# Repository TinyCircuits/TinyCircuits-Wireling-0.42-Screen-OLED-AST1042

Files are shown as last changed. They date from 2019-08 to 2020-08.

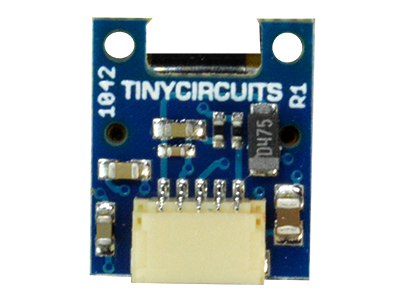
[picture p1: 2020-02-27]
images/AST1042-Learn-Photo-02.png

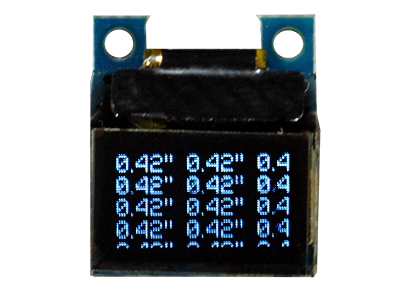
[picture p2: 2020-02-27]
images/AST1042-Learn-Photo-01.png

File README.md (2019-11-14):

# TinyCircuits Wireling 0.42 Screen OLED
# AST1042 Rev1

The design files are located under design_files/ for the TinyCircuits AST1042 Rev 1 PCB. This is a Wireling board which is the smallest our line has to offer, still packing an impressive 72 x 40 pixels in a 0.42" package for all your tiny display needs.

Format is in Cadsoft Eagle format - Eagle version 6.2 was used for the original design.

For more infomation on this, check out the product page at TinyCircuits.com

# License:

Design by TinyCircuits.
All design files are released under the Creative Commons Attribution Share-Alike 3.0 License, see the following link for details: http://creativecommons.org/licenses/by-sa/3.0

All text above must be included in any redistribution or derived design

This project uses designs and concepts developed as part of the Arduino project and the LilyPad project.  The TinyCircuits design files themselves (schematics, PCB and libraries) are not directly derived from these works' design files and have been created new, however the concepts and basic architecture behind the TinyDuino and TinyLily products are derived and we thank the hard work of the organizations below for their contributions to open-source hardware:
  
Original Arduino Uno Design by Team Arduino

LilyPad Arduino Design by Leah Buechley and Sparkfun Electronics

Please support the open-source hardware community

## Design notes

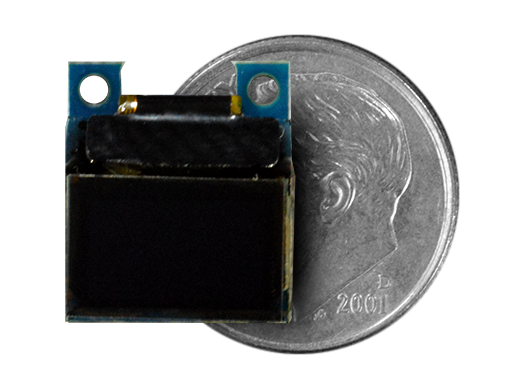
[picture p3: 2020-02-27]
images/AST1042-Product-Photo-03.png

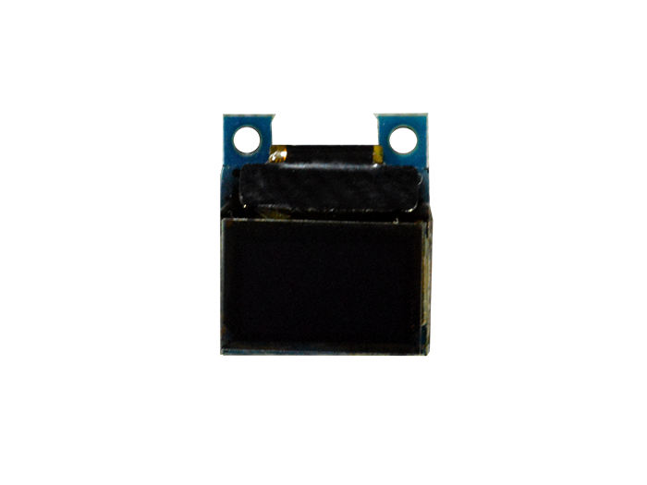
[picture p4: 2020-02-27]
images/AST1042-Product-Photo-01.png

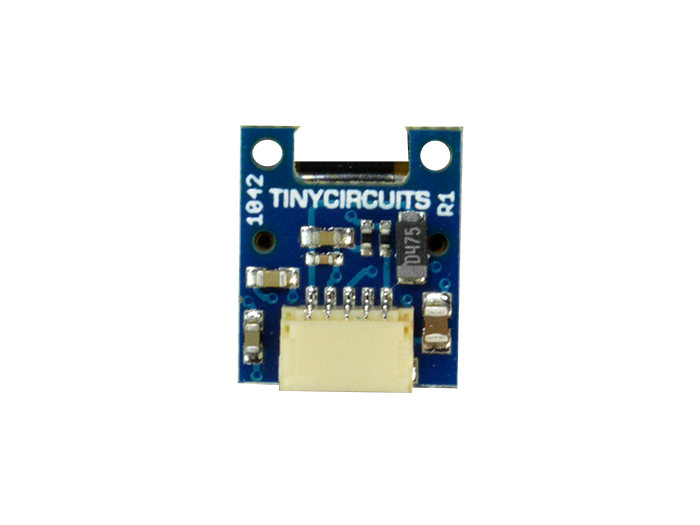
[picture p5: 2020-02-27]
images/AST1042-Product-Photo-02.png

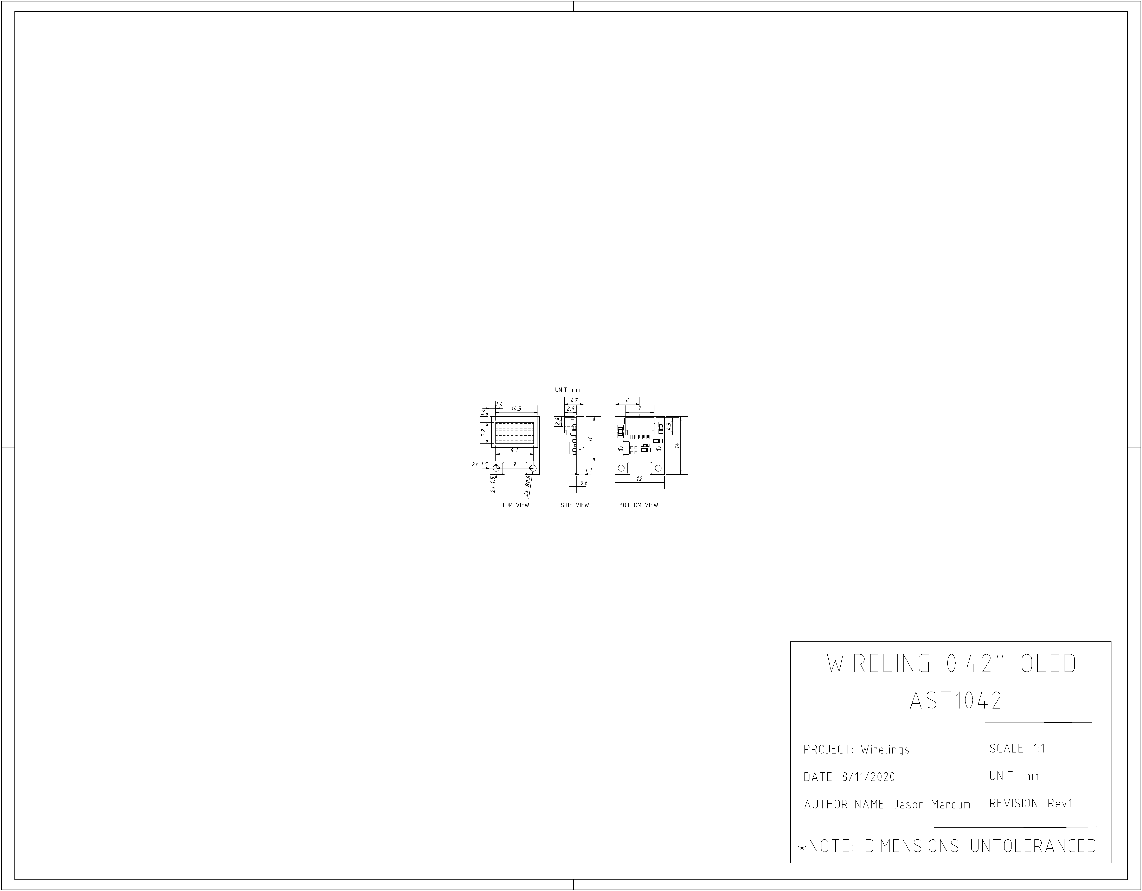
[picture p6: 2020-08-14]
cad/Wireling_042OLED_AST1042_REV1-DETAILED_DRAWING-PNG.png

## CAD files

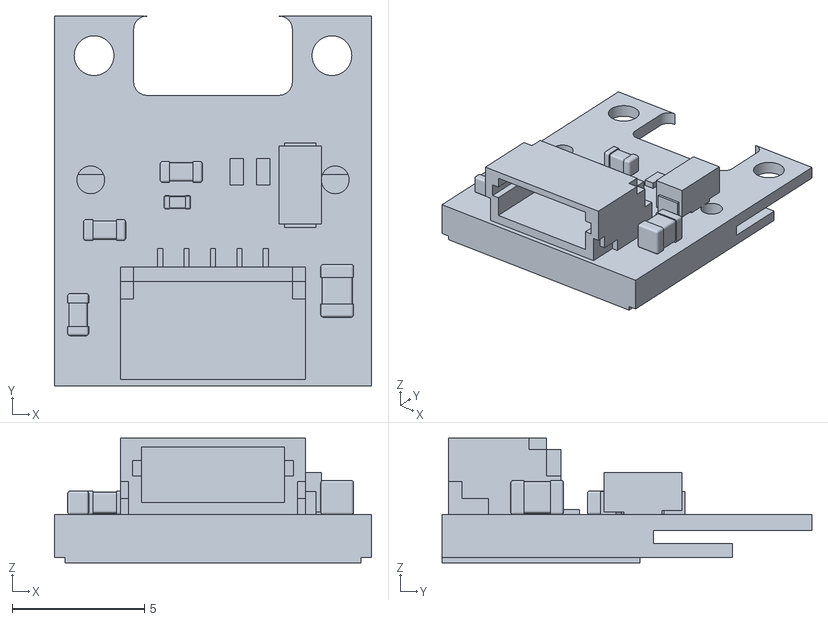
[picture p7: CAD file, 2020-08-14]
cad/Wireling_042OLED_AST1042_REV1-STL.stl
12.0 x 14.0 x 4.72

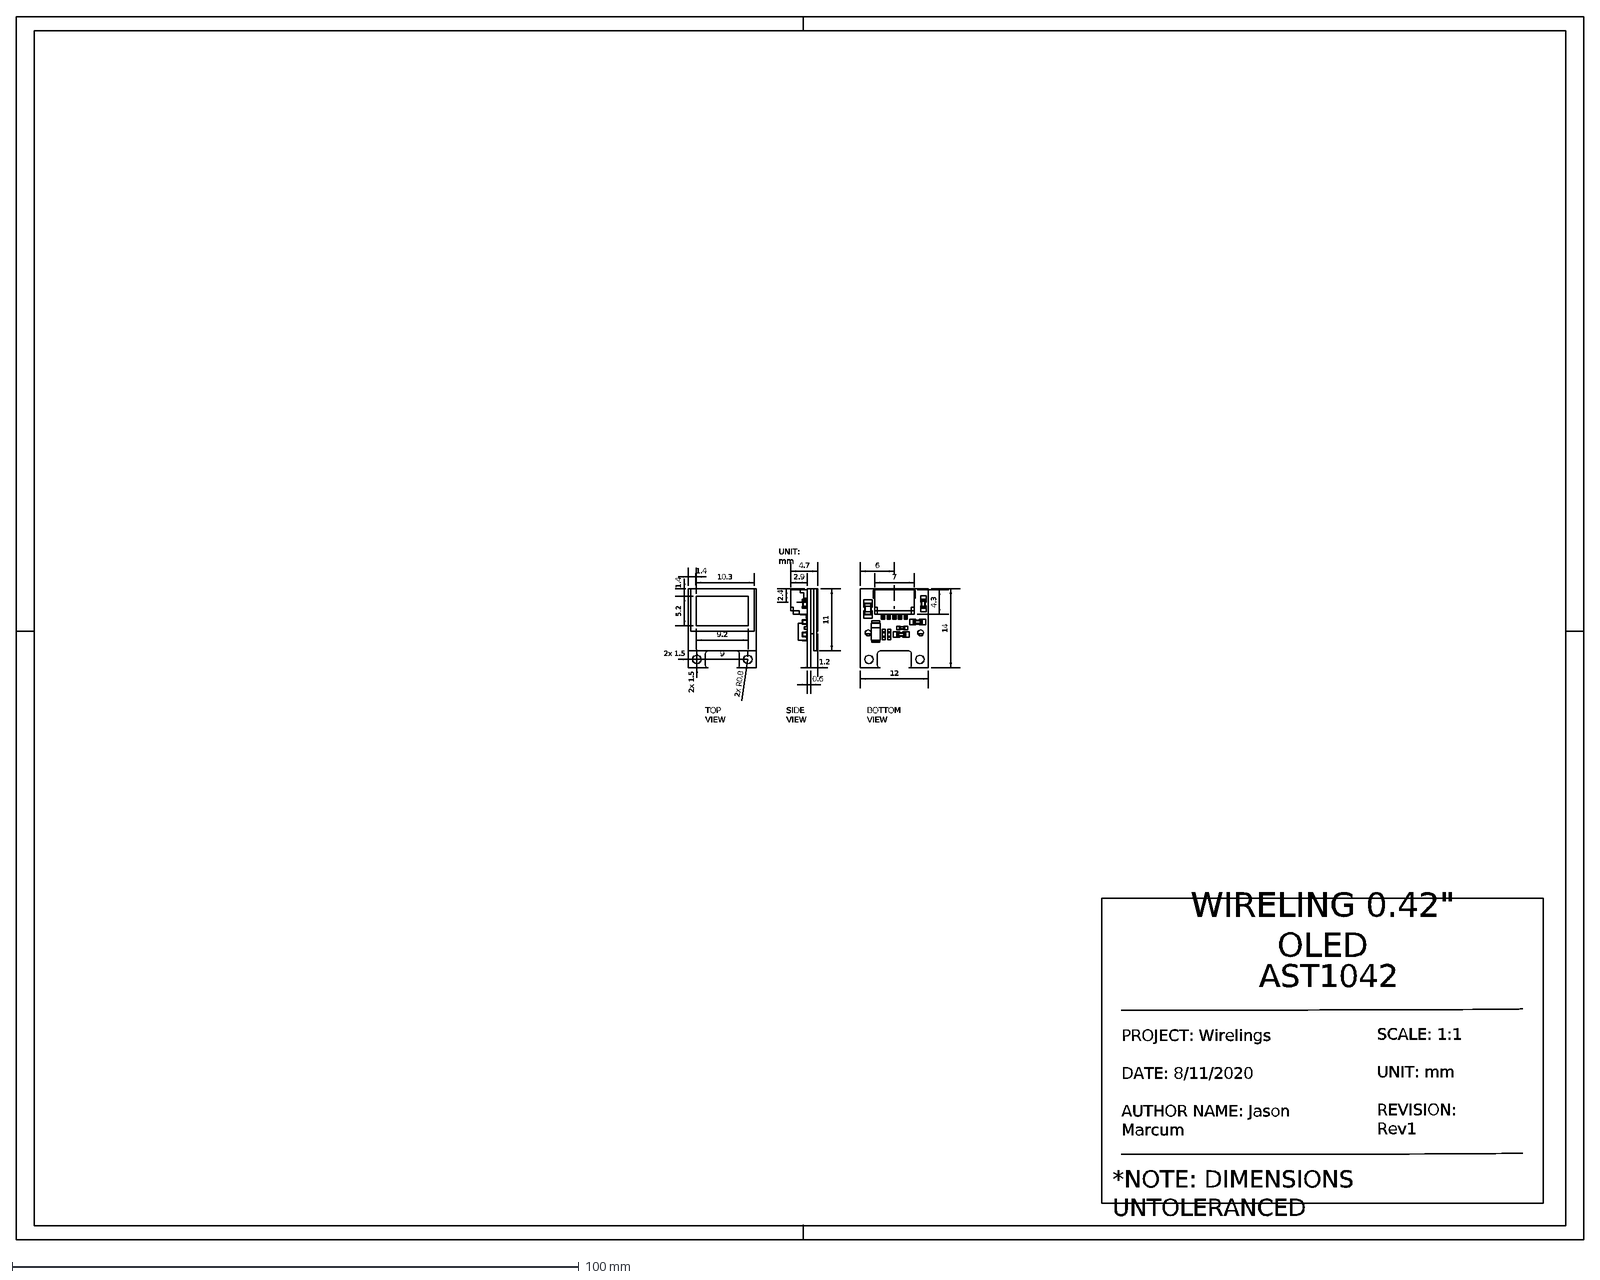
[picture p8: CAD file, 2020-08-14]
cad/Wireling_042OLED_AST1042_REV1-DETAILED_DRAWING-DXF.dxf
*NOTE: DIMENSIONS UNTOLERANCED
SCALE: 1:1 UNIT: mm REVISION: Rev1
TOP VIEW
BOTTOM VIEW
SIDE VIEW
5.2
1.4
2x 1.5
9
2x R0.8
2.4
2.9
4.7
UNIT: mm
1.2
10.3
11
7
6
4.3
14
9.2
0.6
WIRELING 0.42" OLED
AST1042
PROJECT: Wirelings DATE: 8/11/2020 AUTHOR NAME: Jason Marcum
12

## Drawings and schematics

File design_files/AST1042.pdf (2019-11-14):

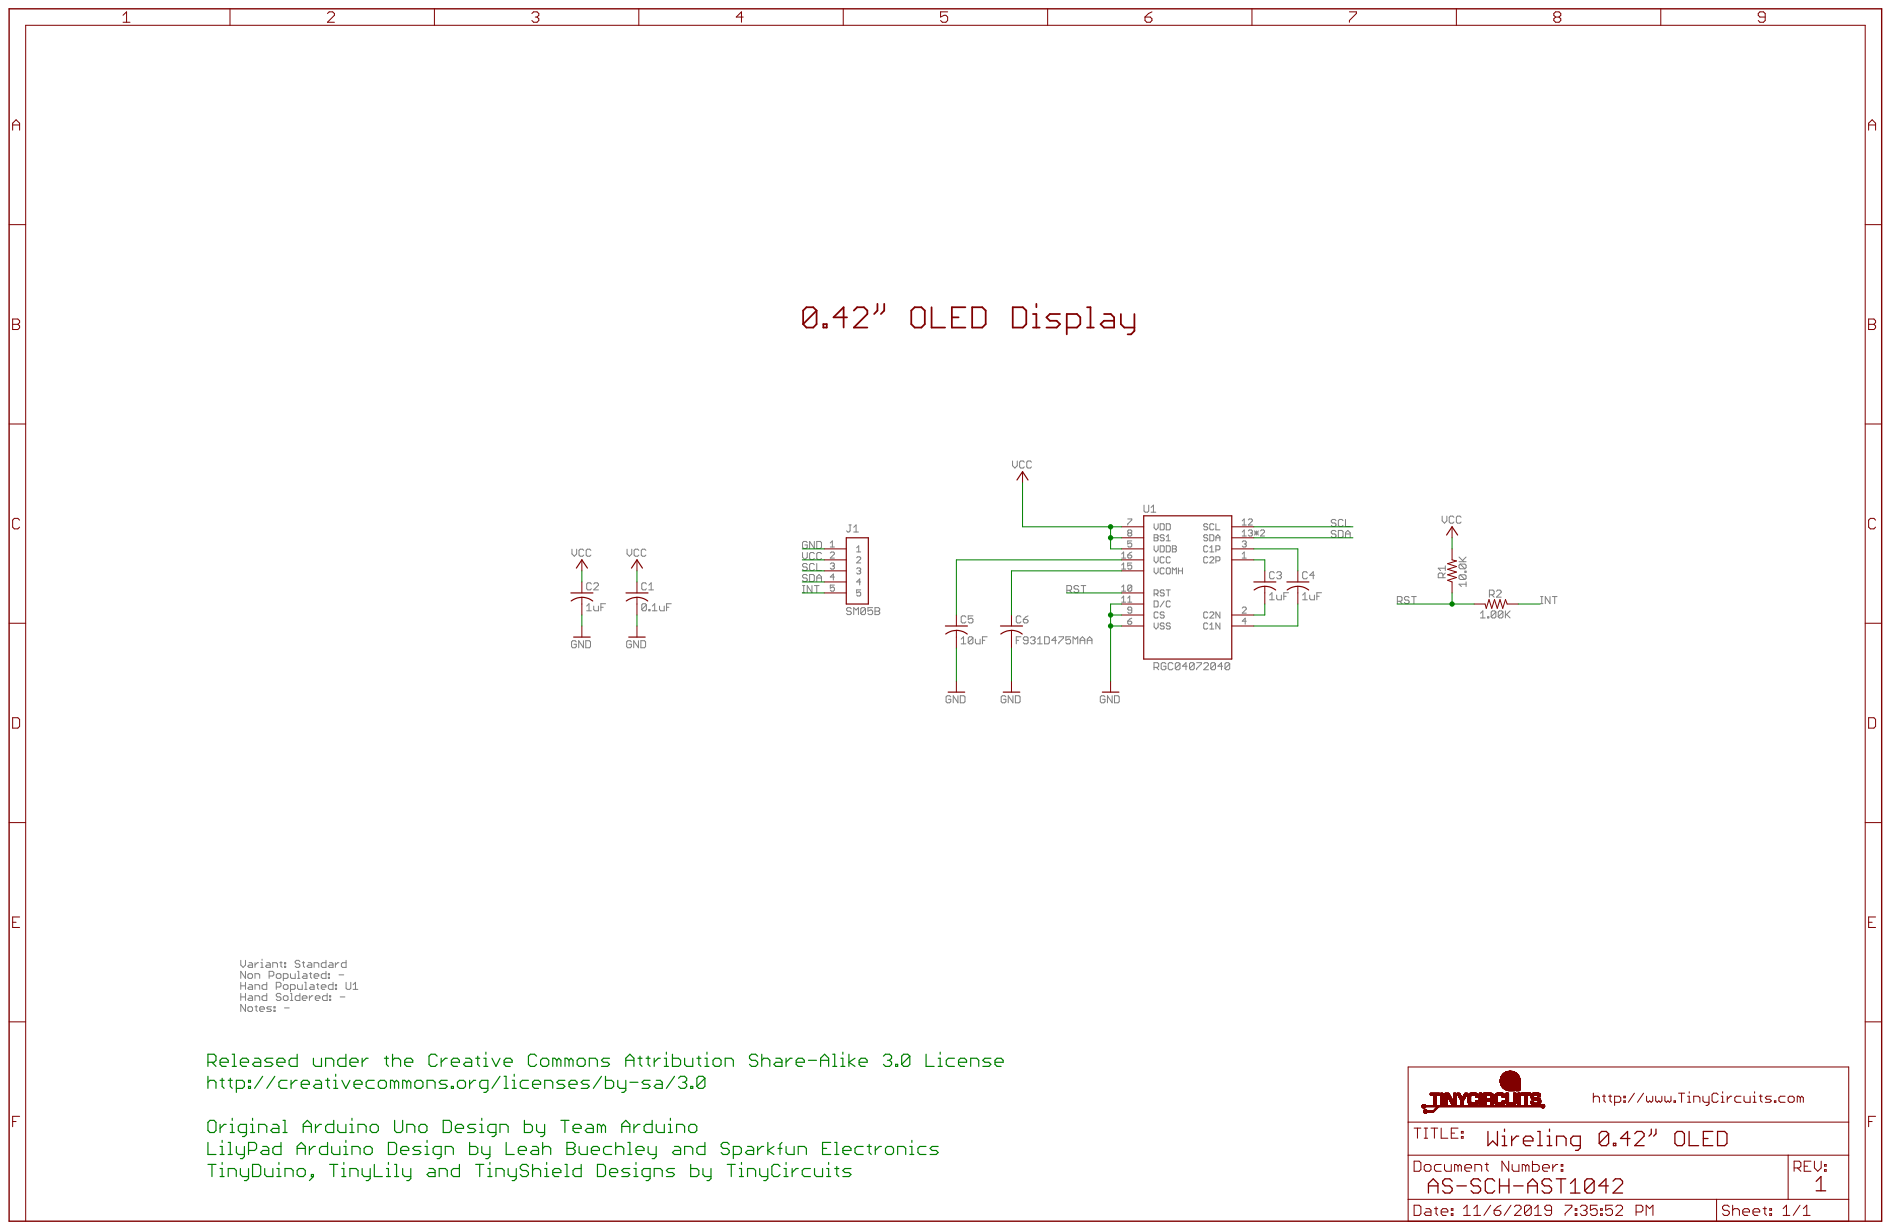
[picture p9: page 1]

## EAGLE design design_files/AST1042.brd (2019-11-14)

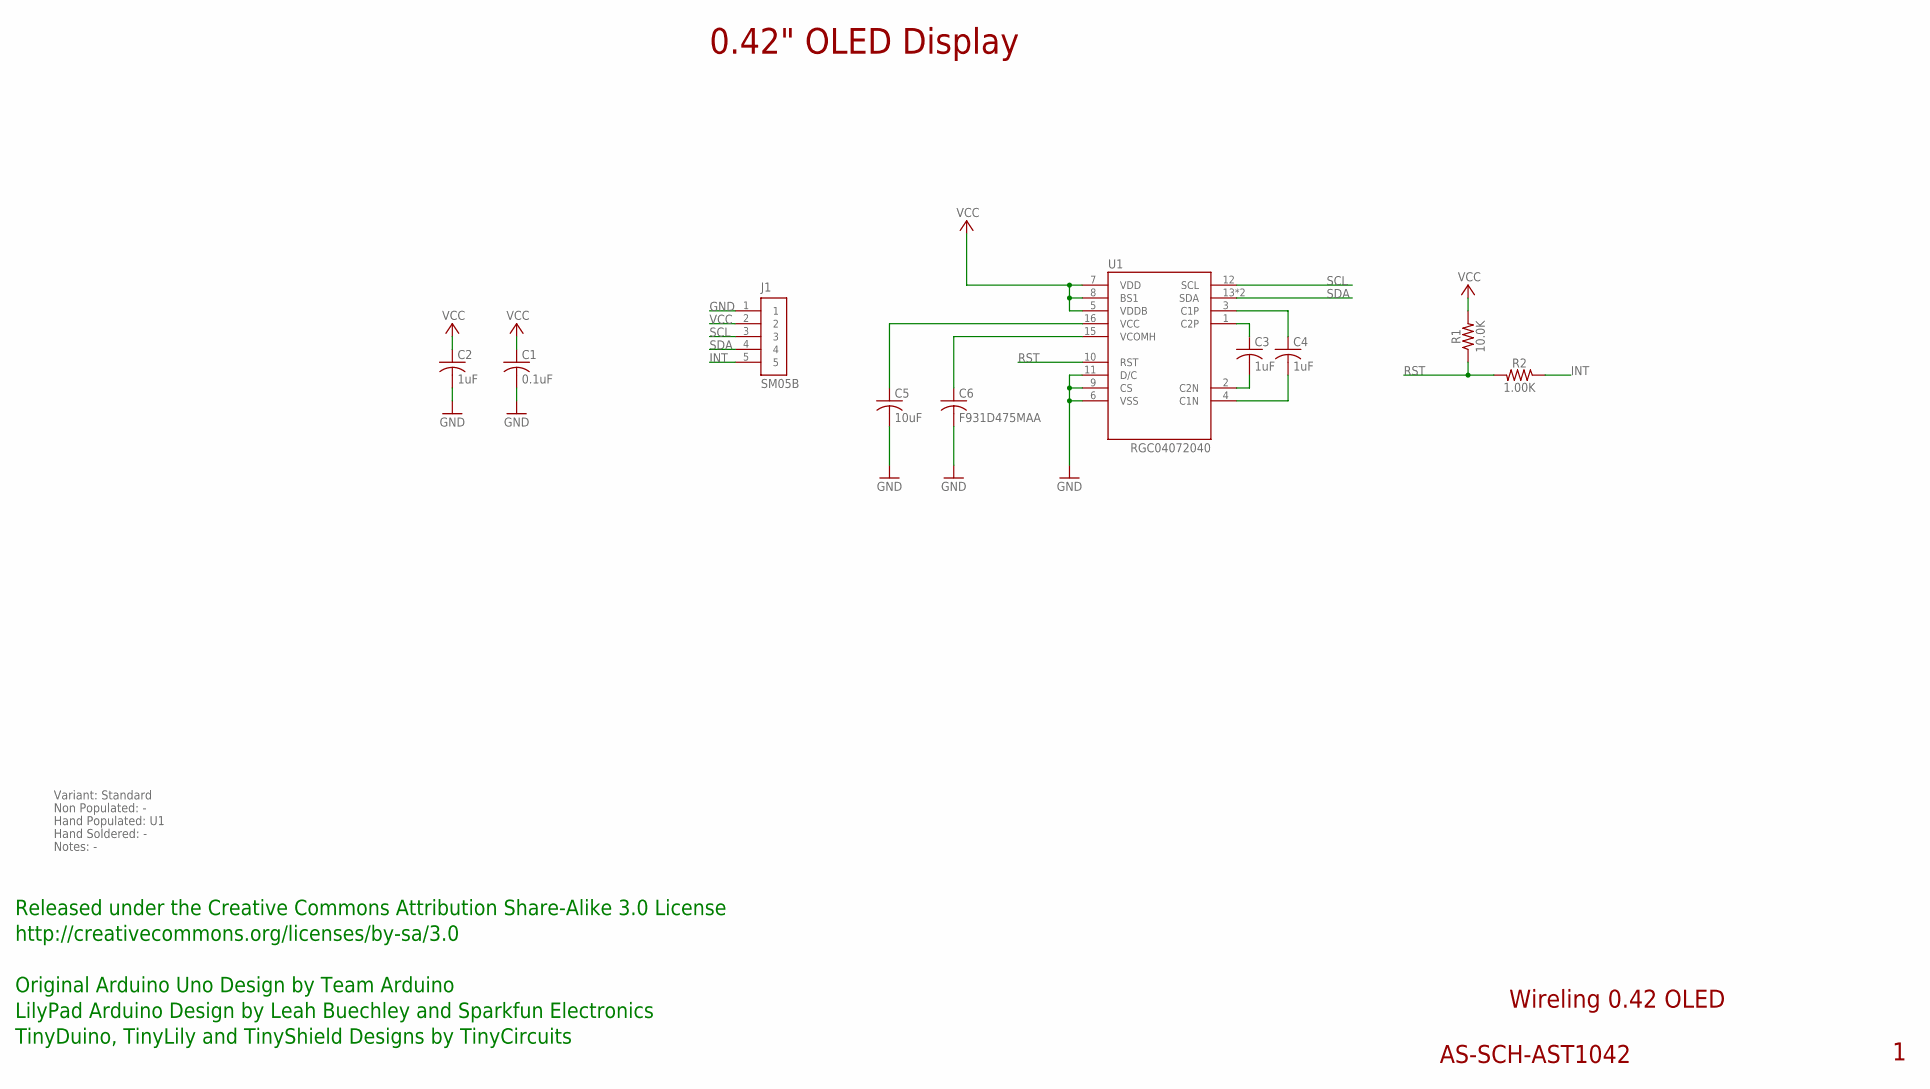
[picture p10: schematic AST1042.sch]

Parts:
C1: 0.1uF; C0402
C2: 1uF; C0603; PARTNO AS-ITM-00410
C3, C4: 1uF; C0603
C5: 10uF; C0805
C6: F931D475MAA; 1206_CAP_TANT
J1: SM05B; JST_SH_5X1_EDGE
R1: 10.0K; 0402
R2: 1.00K; 0402; PARTNO AS-ITM-00003
U1: RGC04072040; OLED_042

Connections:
GND: C1.2, C2.2, C5.2, C6.2, J1.1, U1.6 (VSS), U1.9 (CS), U1.11 (D/C)
INT: J1.5, R2.1
unnamed: C6.1, U1.15 (VCOMH)
unnamed: C3.1, U1.1 (C2P)
unnamed: C5.1, U1.16 (VCC)
unnamed: C4.1, U1.3 (C1P)
unnamed: C3.2, U1.2 (C2N)
unnamed: C4.2, U1.4 (C1N)
RST: R1.1, R2.2, U1.10 (RST)
SCL: J1.3, U1.12 (SCL)
SDA: J1.4, U1.13 (SDA), U1.14 (SDA)
VCC: C1.1, C2.1, J1.2, R1.2, U1.5 (VDDB), U1.7 (VDD), U1.8 (BS1)

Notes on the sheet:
Wireling 0.42 OLED
AS-SCH-AST1042
0.42" OLED Display
Released under the Creative Commons Attribution Share-Alike 3.0 License
http://creativecommons.org/licenses/by-sa/3.0
Original Arduino Uno Design by Team Arduino
TinyDuino, TinyLily and TinyShield Designs by TinyCircuits
LilyPad Arduino Design by Leah Buechley and Sparkfun Electronics
Non Populated: -
Hand Populated: U1
Hand Soldered: -
Variant: Standard
Notes: -

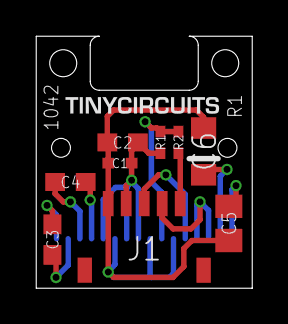
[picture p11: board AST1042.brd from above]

Board: 2 copper layers, 12.0 x 14.0 mm, 11 parts (1 on the bottom side), 12 nets.

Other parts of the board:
U$1: DOCFIELD-TINYCIRCUITS-PCB

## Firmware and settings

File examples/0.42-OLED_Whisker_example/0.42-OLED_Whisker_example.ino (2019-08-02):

/************************************************************************
 * HP7240 WhiskerBoard 0.42" OLED Display Demo/Test Code -
 * This code will display text and a Sprite at the same time when compiled. 
 *
 * Hardware by: TinyCircuits
 * Written by: Ben Rose, Laverena Wienclaw, & Hunter Hykes for TinyCircuits
 *
 * Initiated: Mon. 11/20/2017 
 * Updated: Tue. 08/02/2019
 ************************************************************************/

#include <Wire.h>                   // For I2C communication
#include <TinyScreen.h>             // For interfacing with TinyScreen+
#include "Font_042.h"               // The font displayed on the screen
#include "TinyCircuits_HP7240.h"    // Library for OLED screen
#include "exampleSprites.h"         // Holds arrays of example Sprites

#define SCREEN_PORT 0               // Port used by the 0.42 OLED Whisker
#define RESET_PIN (uint8_t)A0       // A0 corresponds to Port 0. Update if changing ports.
                                    // Port1: A1, Port2: A2, Port3: A3
// Variable for the 0.42" Whisker screen
TinyCircuits_HP7240 TiniestScreen;

#define xMax TiniestScreen.xMax
#define yMax TiniestScreen.yMax

TinyScreen display = TinyScreen(TinyScreenPlus);

// This is the data structure for a TinyScreen Sprite
typedef struct {
  int x;             // X coordinate (top left corner) of where Sprite is placed on screen initially 
  int y;             // Y coordinate (top left corner) of where Sprite is placed on screen initially 
  int width;         // Wideness of Sprite
  int height;        // Height of Sprite
  int bitmapNum;     // Index of animation stage of Sprite (only used when a Sprite is animated)
  const unsigned int * bitmap; // The array of 0's and 1's that determines appearance of Sprite
} Sprite;

Sprite bunnySprite = {0, 0, 13, 13, 0, bunnyBitmap};
Sprite duckSprite = {59, 3, 13, 10, 0, duckBitmap};
int amtSprites = 2; 
Sprite * spriteList[2] = {
  &bunnySprite, &duckSprite
};

uint8_t oledbuf[HP7240_BUFFERSIZE]; // Buffer to hold screen data

int bufIndex = 0; // Buffer index in respect to the array of pixels on the screen
int textPos = 0;  // Used to make text move left or right

int bunnySpeed = 2;
int bleh = 0;

void setup() {
  SerialUSB.begin(9600);
  pinMode(4, OUTPUT);
  digitalWrite(4, HIGH); // power Whisker Adapter TinyShield
  delay(10);

  TiniestScreen.begin();    // begin I2C communications with screen
  selectPort(SCREEN_PORT);  // This port# matches the one labeled on the adapter board
  TiniestScreen.resetScreen(RESET_PIN);   // resets whisker screen MUST BE CALLED BEFORE init()
  TiniestScreen.init();     // initialize screen
  clearOLED();              // Clear Display Buffer, isn't fully cleared here, frame buffer must be sent
  delay(2);
  TiniestScreen.sendFramebuffer(oledbuf); // Send Cleared Buffer

  // Initialize appearance of TinyScreen
  display.begin();
  display.setFlip(true);
  display.setBrightness(15);
  display.setFont(thinPixel7_10ptFontInfo);
  display.fontColor(TS_8b_White, TS_8b_Black); // white text, black background
  display.setCursor(0, 0);
  display.print("0.42 OLED Test");
  
}

// Clear the screen, put new text on the screen -> clear to create scrolling effect 
void loop() {
  clearOLED();
  drawSprites();
  
  textPos = 3*72;
  TiniestScreen.setCursorX(textPos);
  
  TiniestScreen.printSSD(oledbuf, "Bun and Duck"); // text must be written after sprites
  
  TiniestScreen.sendFramebuffer(oledbuf);
}

void selectPort(int port) {
  Wire.beginTransmission(0x70);
  Wire.write(0x04 + port);
  Wire.endTransmission(0x70);
}

/* The OLED screen is 72 by 40 pixels. The screen uses x and y coordinates,
   but with the twist that the 0,0 point is at the top left:

   **************************************************************************
   |  (0,0), (1,0), (...)                                            (71, 0)|
   |  (0,1),                                                                |
   |  (...)                                                                 |
   |                                                                        |
   |                                                                        |
   |                                                                        |
   |  (0,39)                                                         (71,39)|
   **************************************************************************
                              (Not to scale)
  This function draws the Sprite by iterating through y 'slices' to find the x coord
  at which the Sprite starts as defined by the data structure Sprite.
  Each x pixel in these y slices is then flipped on or off using the bool pixelOn

  Fun fact: The x coord must be checked for being on the screen (within 72) due to
  the way the OLED screen works (writes all the information for the top quad of the
  screen before starting the next quad information). That's why there seems to be
  a redundant check for the x coordinate being within position 72.
*/

void drawSprites() {
  clearOLED();

  for (int y = 0; y < yMax; y++) { // Iterates through all y coordinates of the screen
    for (int spriteIndex = 0; spriteIndex < amtSprites; spriteIndex++) { // Iterates pixels for each Sprite

      // Sets currentSprite to the Current Sprite being accessed in the array
      Sprite *currentSprite = spriteList[spriteIndex]; 
      
      // Checks if the current Y-coordinate is within the current sprite's area
      if (y >= currentSprite->y && (y < (currentSprite->y + currentSprite->height))) { 
        int endX = currentSprite->x + currentSprite->width;
        if (currentSprite->x < xMax && endX > 0) { //checks if the sprite is within the X-coordinate bounds of the screen
          int xBitmapOffset = 0;
          int xStart = 0;
          if (currentSprite->x < 0) {
            xBitmapOffset -= currentSprite->x;
          }
          if (currentSprite->x > 0) {
            xStart = currentSprite->x;
          }
          int yBitmapOffset = (y - currentSprite->y) * currentSprite->width;

          for (int x = xStart; x < endX && x < xMax; x++) { //iterates through the X-bounds of the sprite
            bool pixelOn = currentSprite->bitmap[xBitmapOffset + yBitmapOffset++];
            if (pixelOn) {
              setPixel(x, y); //sets the pixel if a 1 is found in the bitmap
            }
          }
        }
      }
    }
  }
}

// Writes blank data to OLED to clear data
void clearOLED() {
  for (int i = 0; i < HP7240_BUFFERSIZE; i++) {
    oledbuf[i] = 0x00;
  }
}

void setPixel(int px, int py) {
  int pos = px;       //holds the given X-coordinate
  if (py > 7) { // if Y > 7 (the number of indices in a byte)
    pos += (py/8)*xMax; // bump down to the next row by increasing X by the screen width by the number of necessary rows
  }
  py = (py % 8);  // adjusts Y such that it can be written within the 0-7 bounds of a byte
  oledbuf[pos] |= (1 << (py)); // the bits of the byte within the buffer are set accordingly by placing a 1 in the respective bit location of the byte
}

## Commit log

2019-11-14 update naming
    [AST1042.brd, AST1042.sch]
2020-08-14 Add CAD data
    [Wireling_042OLED_AST1042_REV1-DETAILED_DRAWING-DXF.dxf, Wireling_042OLED_AST1042_REV1-STL.stl]
